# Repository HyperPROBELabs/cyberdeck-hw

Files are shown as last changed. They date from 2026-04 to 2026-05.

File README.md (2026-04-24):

# cyberdeck-hw

Hardware design repository for the Cyberdeck platform
by **Kali Assistant** — HyperPROBE Labs

---

## Overview

This repository contains the **hardware design files** for the Cyberdeck project, including:

* PCB schematics and layouts
* mechanical CAD models
* fabrication and manufacturing data
* supporting hardware resources

The goal is to provide a **modular, reproducible, and hackable hardware platform** for embedded systems, networking, and cybersecurity applications.

---

## Usage

You are free to:

* study the design
* modify and improve it
* manufacture and sell derived hardware
* integrate it into your own systems

Please review the license terms below before use.

---

## Licensing

Unless otherwise specified, this repository is licensed as follows:

### Hardware

All hardware design files are licensed under the
CERN Open Hardware Licence Version 2 - Permissive.

---

### Documentation

All documentation (e.g., manuals, images, diagrams) is licensed under the
Creative Commons Attribution 4.0 International.

---

### Subdirectory Overrides

If a subdirectory contains its own license file or license header:

> **That license takes precedence for files within that subdirectory.**

---

## Attribution

When redistributing or using this work, please attribute:

Kali Assistant

HyperPROBE Labs

---

## Contributing

Contributions are welcome, including:

* hardware improvements
* PCB optimization
* mechanical refinements
* documentation updates

Please ensure:

* proper attribution is maintained
* SPDX license identifiers are included where applicable

---

## Disclaimer

This hardware is provided **"AS IS"**, without warranty of any kind.
Use at your own risk.

---

## Notes

* This is an evolving hardware platform
* Designs may change between revisions
* Not all files are guaranteed to be production-ready

---

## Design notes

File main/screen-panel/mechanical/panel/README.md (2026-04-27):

# Screen Panel

This directory contains the **Cyberdeck Screen Panel (Main)** 3D STEP files and related production resources.

---

## Status

**April 27, 2026**
Design and prototyping in progress.

---

## Directory Structure

```
./production/
├── parts/                 # STEP files for CNC machining and full models
├── mesh-3d-printing/      # STL files for components intended for 3D printing
```

* `./production/parts/`
  Contains STEP files for CNC fabrication and complete mechanical models.

* `./production/mesh-3d-printing/`
  Contains STL meshes for parts that should be 3D printed.

---

## Main Assembly File

* `./pannel.step.xz`

This is the **full screen panel assembly** in STEP format, compressed using `xz` due to file size limitations.

### Usage

```bash
xz -dk panel.step.xz
```

After decompression, import the `.step` file into your preferred CAD software.

---

## Design Notes

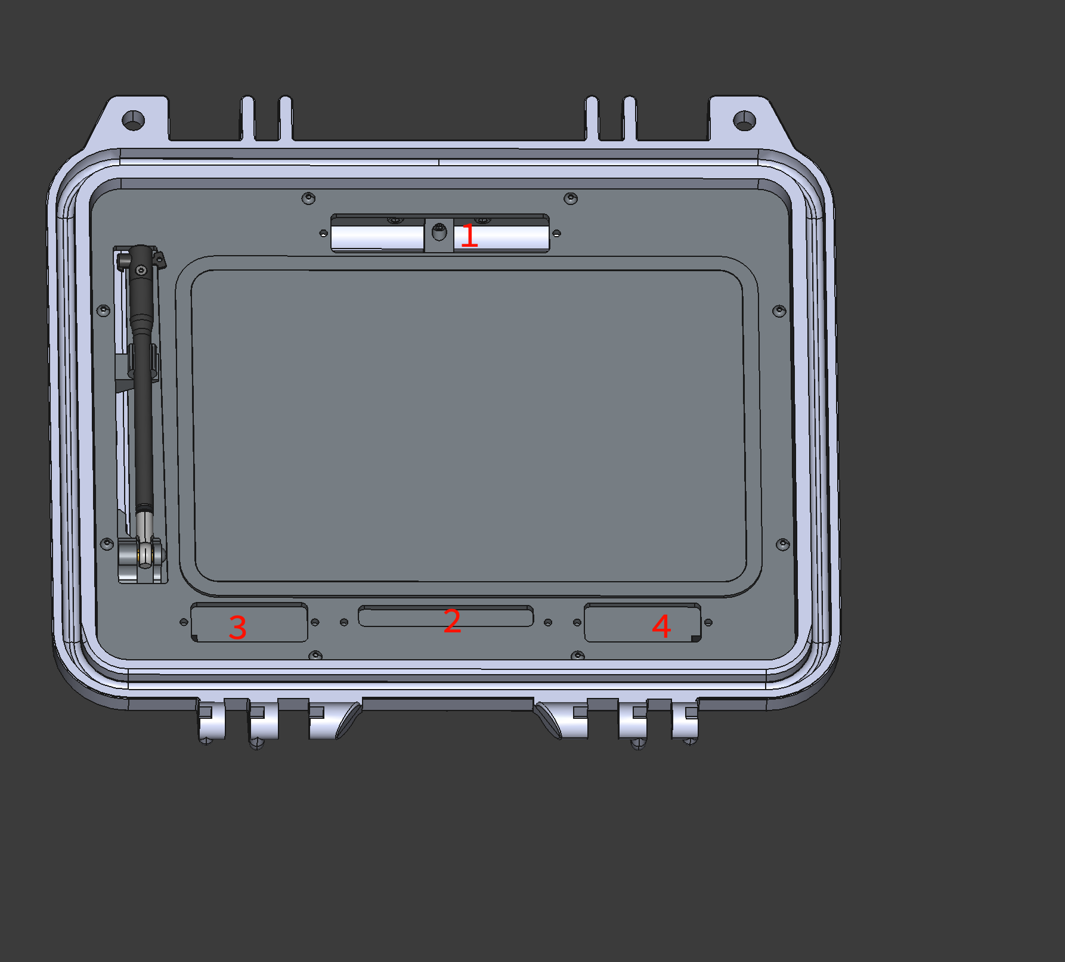
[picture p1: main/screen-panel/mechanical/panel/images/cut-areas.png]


The main plate (aluminum sheet metal) includes several reserved cut areas for future expansion:

### Area 1 — Camera Module (Future)

Reserved cutout for a potential Raspberry Pi camera integration.

### Area 2 — Antenna & Signal Routing

Reserved space for:

* Antenna feed lines
* Flexible Printed Circuits (FPCs)
* Internal signal routing to the Cyberdeck bottom connector

**Note:**
Cables/FPCs are intended to be bundled and protected using TPU, forming a flat, reinforced structure similar to a *flat USB cable* (conceptually: `|:|`).

### Area 3 & 4 — Expansion Modules

Reserved cutouts for optional add-ons, such as:

* Small OLED/TFT displays
* Indicator LEDs
* Buttons or control interfaces

---

## Notes

* This design is modular and intended for iterative hardware expansion.
* Cut areas are intentionally reserved to support future features without redesigning the main plate.
* Mechanical and electrical integration (especially FPC routing) should be considered during assembly.

This project is under active development. Dimensions, cutouts, and interfaces may change between revisions.

---

Cyberdeck Project
Designed by Kali Assistant

Copyright (c) 2026 HyperPROBE Labs. All Rights Reserved.

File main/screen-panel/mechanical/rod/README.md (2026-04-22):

# Screen Panel Support Rod (ROD)

This directory contains the **Cyberdeck Screen Panel Support Rod** 3D STEP files and production resources.

---

# Directory Structure

The repository tree should look like this:

```
/
├── ...
├── docs
│   └── screen-panel-support-rod_manufacturing-and-assembly-manual.pdf
├── main/
│   └── screen-panel/
│       ├── mechanical/
│       │   └── rod/
│       │       ├── production/
│       │       │   ├── bom.csv
│       │       │   ├── mesh-3d-printing/
│       │       │   │   ├── rod-body.stl
│       │       │   │   ├── rod-hat.stl
│       │       │   │   ├── rod-latch.stl
│       │       │   │   └── rod-washer-gasket-multiple-sizes.stl
│       │       │   ├── rod-body.step
│       │       │   ├── rod-hat.step
│       │       │   ├── rod-latch.step
│       │       │   ├── rod-washer-gasket-multiple-sizes.step
│       │       │   └── spring-techdraw.pdf
│       │       ├── README.md
│       │       └── rod.step
│       └── ...
└── ...
```

---

# Production Files

Inside the `production` directory:

* Files located in `mesh-3d-printing/` are **STL mesh files**
* These files are intended for **3D printing manufacturing**
* STEP files are intended for **CNC machining or CAD modification**

---

# Manufacturing

Please read the manufacturing and assembly manual before production:

```
/docs/screen-panel-support-rod_manufacturing-and-assembly-manual.pdf
```

Or open directly:

[`../../../../docs/screen-panel-support-rod_manufacturing-and-assembly-manual.pdf`](../../../../docs/screen-panel-support-rod_manufacturing-and-assembly-manual.pdf)

Refer to the manual for:

* Manufacturing requirements
* Material specifications
* Assembly instructions
* Hardware details

---

# BOM List

The BOM list is located at:

```
production/bom.csv
```

For detailed BOM information, refer to **Section 3** of the [manual](../../../../docs/screen-panel-support-rod_manufacturing-and-assembly-manual.pdf).

---

# BOM Notes

The following notes are used in the BOM file:

* **Available**
  The part can be purchased or imported, but does **not** guarantee stock availability.

* **Not available**
  The part cannot be legally obtained or imported in some countries or regions.

* **Modify REQ**
  Hardware modification required. Not usable out-of-box. Warranty may be void.

* **Import WARN**
  Import may require license, certification, or documentation.

* **Custom**
  Custom-manufactured part. May require MOQ (Minimum Order Quantity).

### Example

* RF modules capable of transmission may require FCC / CE certification depending on region.

---

# License

This directory (`rod`) and the associated documentation:

```
/docs/screen-panel-support-rod_manufacturing-and-assembly-manual.pdf
```

are licensed under:

**CERN-OHL-P v2**

Notes:

* This license applies **only** to the `rod` directory
* The license **may differ** from the root repository license
* If conflicts occur, the license specified in this directory takes precedence

---

# Notes

* STEP files are provided for manufacturing and modification
* STL files are provided for rapid prototyping and 3D printing
* Always review the manual before manufacturing

---

Cyberdeck Project
Designed by KaliAssistant

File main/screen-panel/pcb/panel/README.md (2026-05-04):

# Screen Panel PCB

This directory contains the PCB design and layout files for the Cyberdeck **screen panel module**.

---

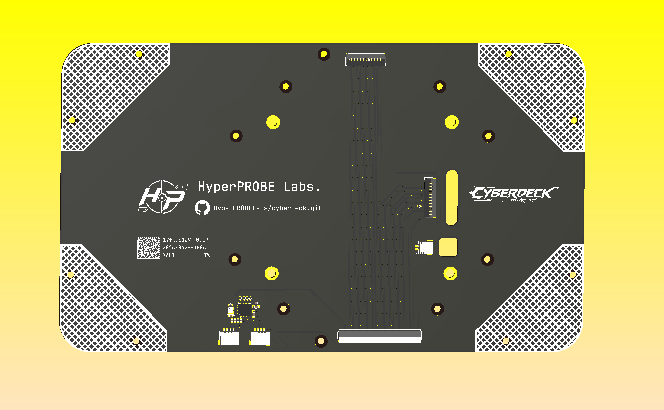
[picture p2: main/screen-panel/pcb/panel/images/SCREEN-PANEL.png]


## Status

**April 29, 2026**
Design and prototyping in progress.

---

## Directory Structure

```
./production/
├── GERBER-*.zip   # Manufacturing files for PCB fabrication
├── BOM-*.csv      # Bill of Materials
└── CPL-*.csv      # Component Placement List (Pick & Place)

./panel-pcb-model*.step.xz  # Compressed 3D STEP model of the PCB
```

---

## 3D Model Usage

Due to GitHub file size limits, the PCB 3D model is compressed using `xz`.

To extract:

```bash
xz -dk panel-pcb-model.step.xz
```

You can then import the `.step` file into your CAD software.

---

## Design Overview

### 50-Pin FPC Integration

The PCB integrates both the camera interface and the Raspberry Pi Touch Display v2 through a **combined 50-pin FPC (Flexible Printed Cable)**.

* FPC design is currently in progress
* Intended to reduce cabling complexity between modules

---

### USB Hub Integration

The board includes a **USB2422 USB hub**, enabling expansion capabilities for the panel.

Two onboard USB expansion module slots are provided for future customization.

---

### Camera Module

Sourcing standalone CMOS sensors is difficult, so the current approach is:

* Use the **Raspberry Pi Camera Module v3 (NoIR)**
* Remove (de-solder) the CMOS module
* Integrate it into this custom PCB design

The camera base and mounting design are still under development.

---

### USB Expansion Modules

Two optional USB-connected addon module slots are included.

Potential use cases:

* Small OLED or TFT displays
* Status indicator LEDs
* Buttons or control interfaces

These modules connect to the onboard USB hub and communicate back to the Cyberdeck motherboard via the 50-pin FPC.

---

## Notes

* This is an actively evolving design
* Hardware, pinout, and module layout may change during prototyping
* Contributions and ideas for USB expansion modules are welcome

---

Cyberdeck Project
Designed by Kali Assistant

Copyright (c) 2026 HyperPROBE Labs. All Rights Reserved.

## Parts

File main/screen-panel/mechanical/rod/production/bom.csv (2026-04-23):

No. | Quantity | Comment | Value | Option | Link | Status
CYB-ROD-001 | 1 | Rod-End-Bearing | M3/1:10RC | (any color) | https://a.co/d/0heQlGqN | Available
CYB-ROD-002 | 1 | Metric Flat Washer | M3 D6/3.2 T0.5 | M3x6mmx0.5mm | https://a.co/d/0e98ipRb | Available
CYB-ROD-003 | 1 | TPU Gasket | -- | -- | -- | Custom
CYB-ROD-004 | 1 | Rod-Body | -- | -- | -- | Custom
CYB-ROD-005 | 1 | Metric Hex Nut | M2x0.4x1.2 | M2 50pcs | https://a.co/d/08POY6ck | Available
CYB-ROD-006 | 1 | Torsion Spring | -- | -- | -- | Custom
CYB-ROD-007 | 1 | Rod-Latch | -- | -- | -- | Custom
CYB-ROD-008 | 1 | Rod-Hat | -- | -- | -- | Custom
CYB-ROD-009 | 1 | Ultra-Low Head Hexalobular Screw | M2x0.4x8 | 50pcs M2/8mm | https://a.co/d/05IATbxW | Available

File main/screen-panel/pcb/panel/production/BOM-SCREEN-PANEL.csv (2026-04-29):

Comment | Designator | Footprint | LCSC | Quantity
100nF | C1,C4,C5 | C_0402_1005Metric | C437421 | 3
10k | R3 | R_0402_1005Metric | C71617 | 1
10nF | C6 | C_0402_1005Metric | C85973 | 1
12k | R2 | R_0402_1005Metric | C481938 | 1
18pF | C7,C8 | C_0402_1005Metric | C161176 | 2
1uF | C2,C3 | C_0603_1608Metric | C77386 | 2
24Mhz | X1 | CRYSTAL-SMD_4P-L2.0-W1.6-BL | C255882 | 1
2k2 | R1 | R_0402_1005Metric | C82680 | 1
47k | R4,R5,R6 | R_0402_1005Metric | C482184 | 3
BUS | FPC2 | FPC-SMD_50P-P0.50_FH34SRJ-50S-0.5SH | C3169104 | 1
SM02B-SRSS-TB | CN1 | CONN-SMD_2P-P1.00_SM02B-SRSS-TB-LF-SN | C160402 | 1
SM04B-SRSS-TB | CN2,CN3 | CONN-SMD_4P-P1.00_SM04B-SRSS-TB-LF-SN | C160404 | 2
USB2422/MJ | U1 | QFN-24_L4.0-W4.0-P0.50-BL-EP2.6 | C633330 | 1
~ | FPC1,FPC3 | FFC-SMD_22P-P0.50_HRS_FH34SRJ-22S-0.5SH | C2889325 | 2

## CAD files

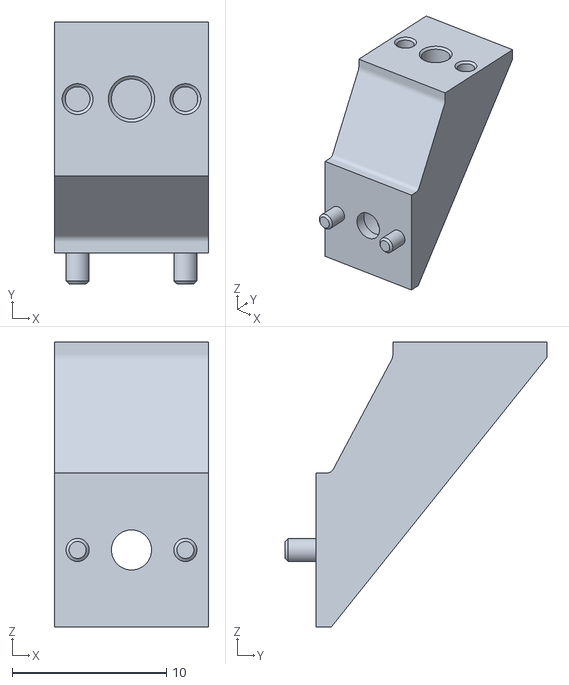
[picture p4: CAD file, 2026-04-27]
main/screen-panel/mechanical/panel/production/mesh-3d-printing/main-frame-angle-bracket.stl
10.0 x 17.0 x 18.5

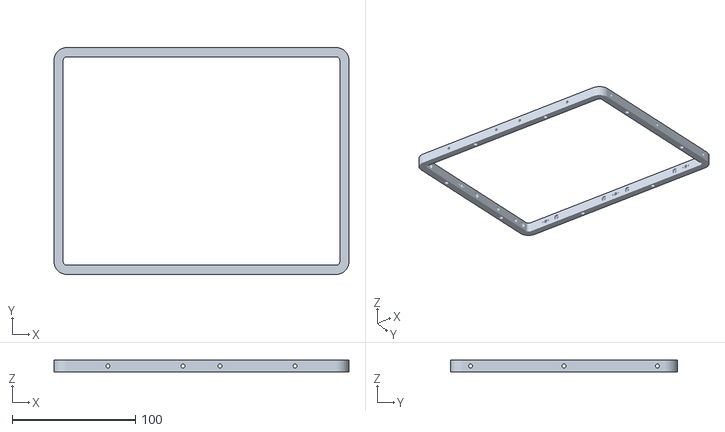
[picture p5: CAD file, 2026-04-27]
main/screen-panel/mechanical/panel/production/mesh-3d-printing/main-frame.stl
239.5 x 184.2 x 10.0

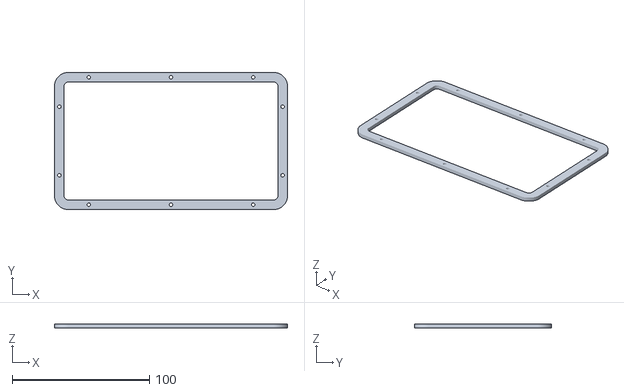
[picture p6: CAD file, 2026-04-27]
main/screen-panel/mechanical/panel/production/mesh-3d-printing/screen-main-base-frame.stl
170.0 x 100.0 x 3.00

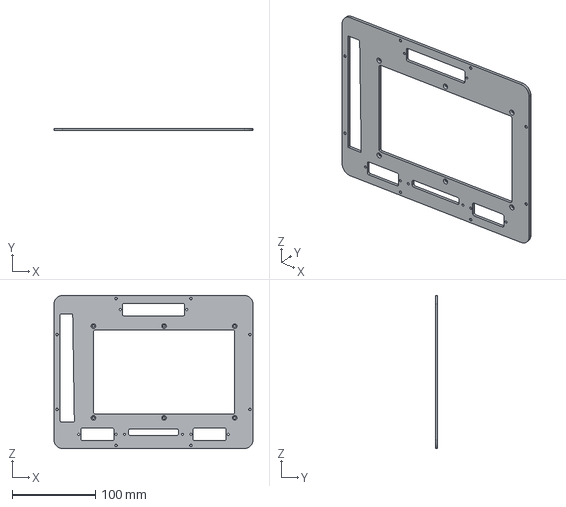
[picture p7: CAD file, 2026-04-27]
main/screen-panel/mechanical/panel/production/parts/main-plate.step
239.5 x 3.00 x 184.2 mm

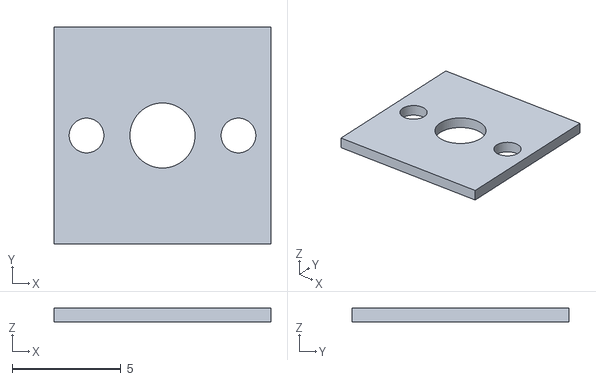
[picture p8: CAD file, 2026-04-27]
main/screen-panel/mechanical/panel/production/mesh-3d-printing/main-frame-angle-bracket-tpu.stl
10.0 x 10.0 x 0.65

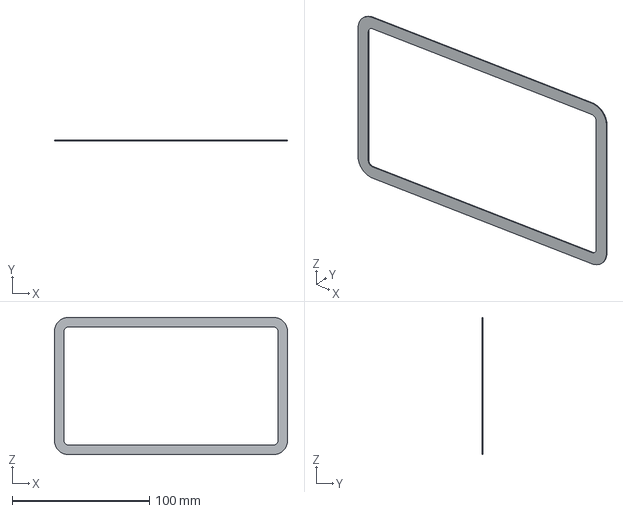
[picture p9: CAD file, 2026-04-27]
main/screen-panel/mechanical/panel/production/parts/screen-main-base-frame-tpu.step
170.0 x 0.55 x 100.0 mm

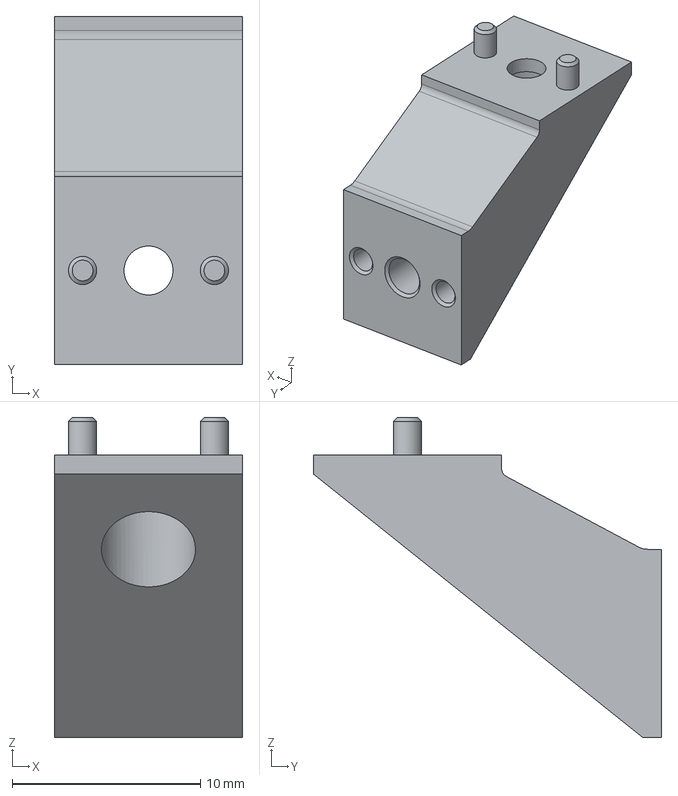
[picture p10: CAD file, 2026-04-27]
main/screen-panel/mechanical/panel/production/parts/main-frame-angle-bracket.step
10.0 x 18.5 x 17.0 mm

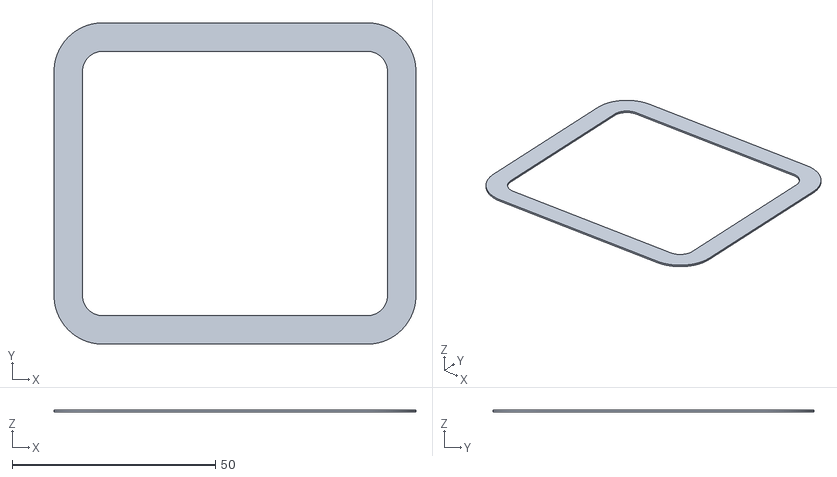
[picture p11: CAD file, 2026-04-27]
main/screen-panel/mechanical/panel/production/mesh-3d-printing/screen-base-tpu.stl
89.0 x 79.0 x 0.55

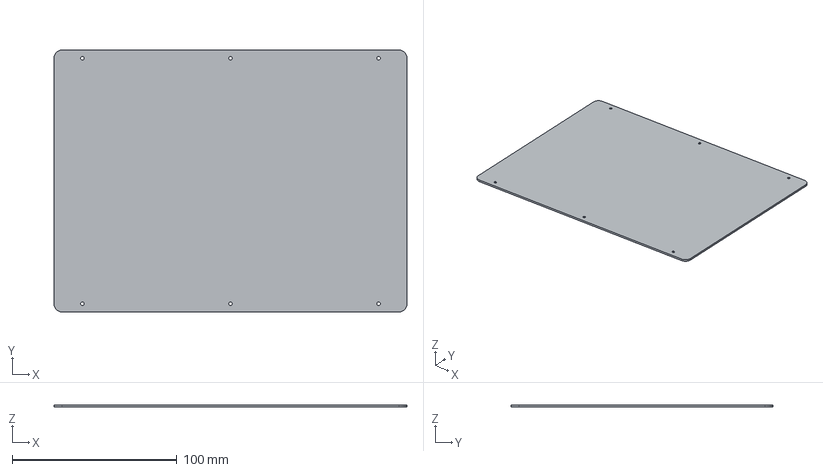
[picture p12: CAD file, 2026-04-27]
main/screen-panel/mechanical/panel/production/parts/base-plate.step
214.5 x 159.2 x 1.50 mm

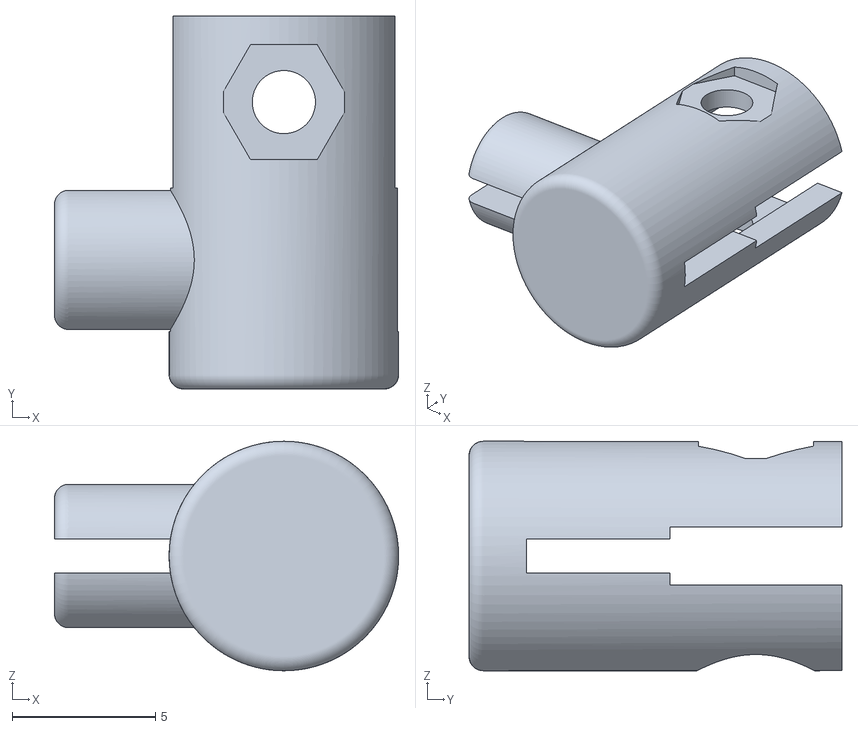
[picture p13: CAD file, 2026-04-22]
main/screen-panel/mechanical/rod/production/mesh-3d-printing/rod-hat.stl
12.0 x 13.0 x 8.00

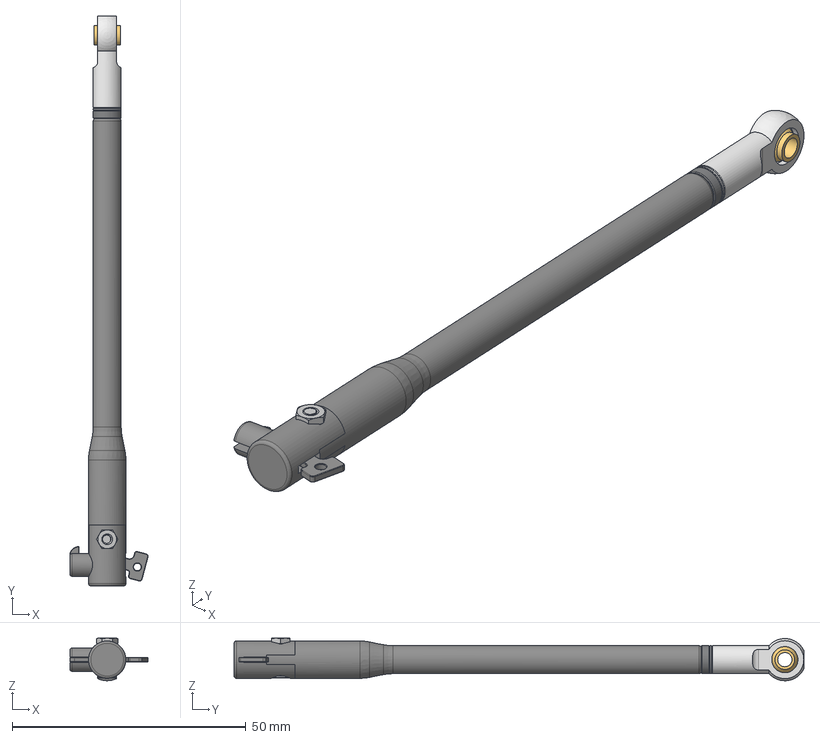
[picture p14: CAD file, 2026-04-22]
main/screen-panel/mechanical/rod/rod.step
16.8 x 121.9 x 9.13 mm
ROLLER
BEARING-HOUSING
BODY-SS316L
LATCH-SS316L
SPRING
CONN-SS316L
TORX-M2-L8MM
NUT-M2-L1MM2
WASHER-PA12
WASHER-SS

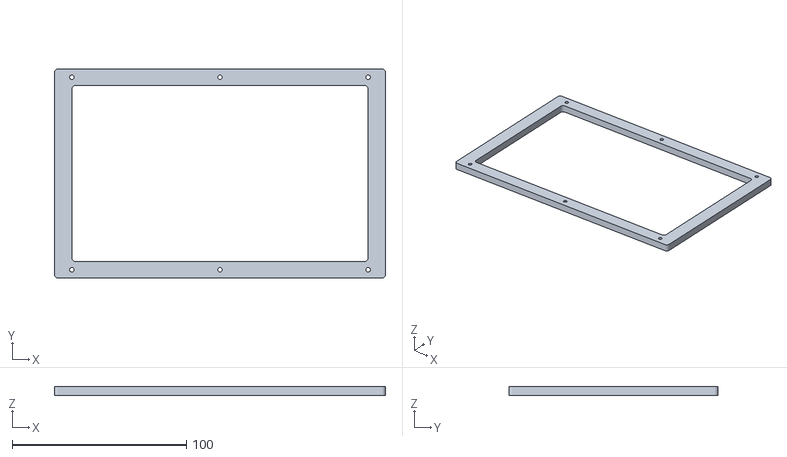
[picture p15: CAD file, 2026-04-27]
main/screen-panel/mechanical/panel/production/mesh-3d-printing/screen-frame.stl
190.0 x 120.0 x 5.00

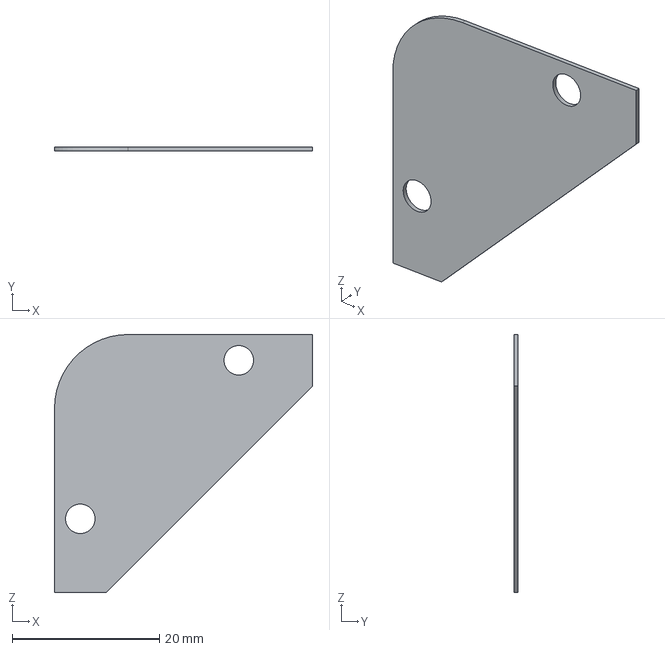
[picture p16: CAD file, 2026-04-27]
main/screen-panel/mechanical/panel/production/parts/screen-angle-bracket-tpu.step
35.0 x 0.55 x 35.0 mm

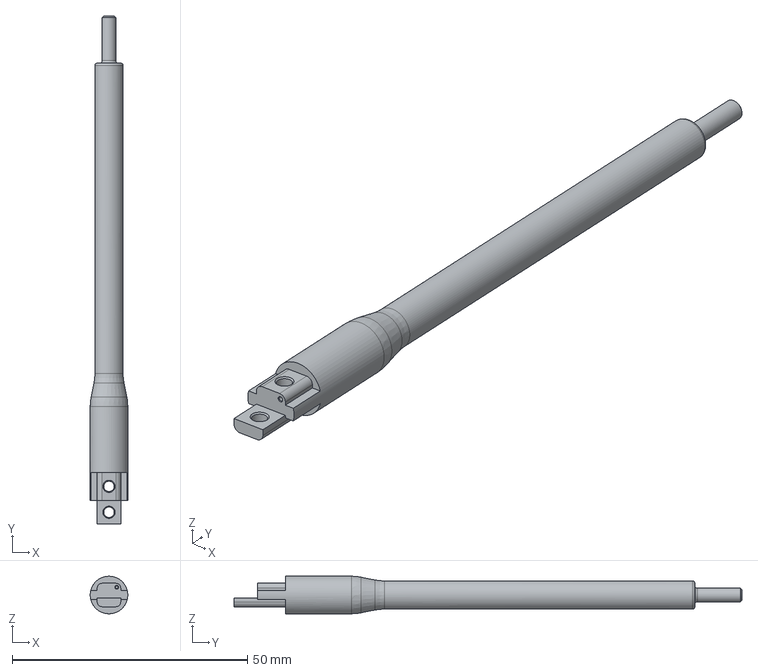
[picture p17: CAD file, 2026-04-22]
main/screen-panel/mechanical/rod/production/rod-body.step
8.00 x 108.0 x 8.00 mm

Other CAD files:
main/screen-panel/mechanical/panel/production/parts/main-frame.step
main/screen-panel/mechanical/panel/production/mesh-3d-printing/screen-main-base-frame-tpu.stl
main/screen-panel/mechanical/panel/production/parts/screen-main-base-frame.step
main/screen-panel/mechanical/panel/production/parts/main-frame-angle-bracket-tpu.step
main/screen-panel/mechanical/panel/production/mesh-3d-printing/rod-holder.stl
main/screen-panel/mechanical/panel/production/mesh-3d-printing/screen-angle-bracket-tpu.stl
main/screen-panel/mechanical/panel/production/mesh-3d-printing/screen-angle-bracket.stl
main/screen-panel/mechanical/panel/production/mesh-3d-printing/screen-base-frame.stl
main/screen-panel/mechanical/panel/production/mesh-3d-printing/screen-tpu.stl
main/screen-panel/mechanical/panel/production/parts/rod-base.step
main/screen-panel/mechanical/panel/production/parts/rod-holder.step
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

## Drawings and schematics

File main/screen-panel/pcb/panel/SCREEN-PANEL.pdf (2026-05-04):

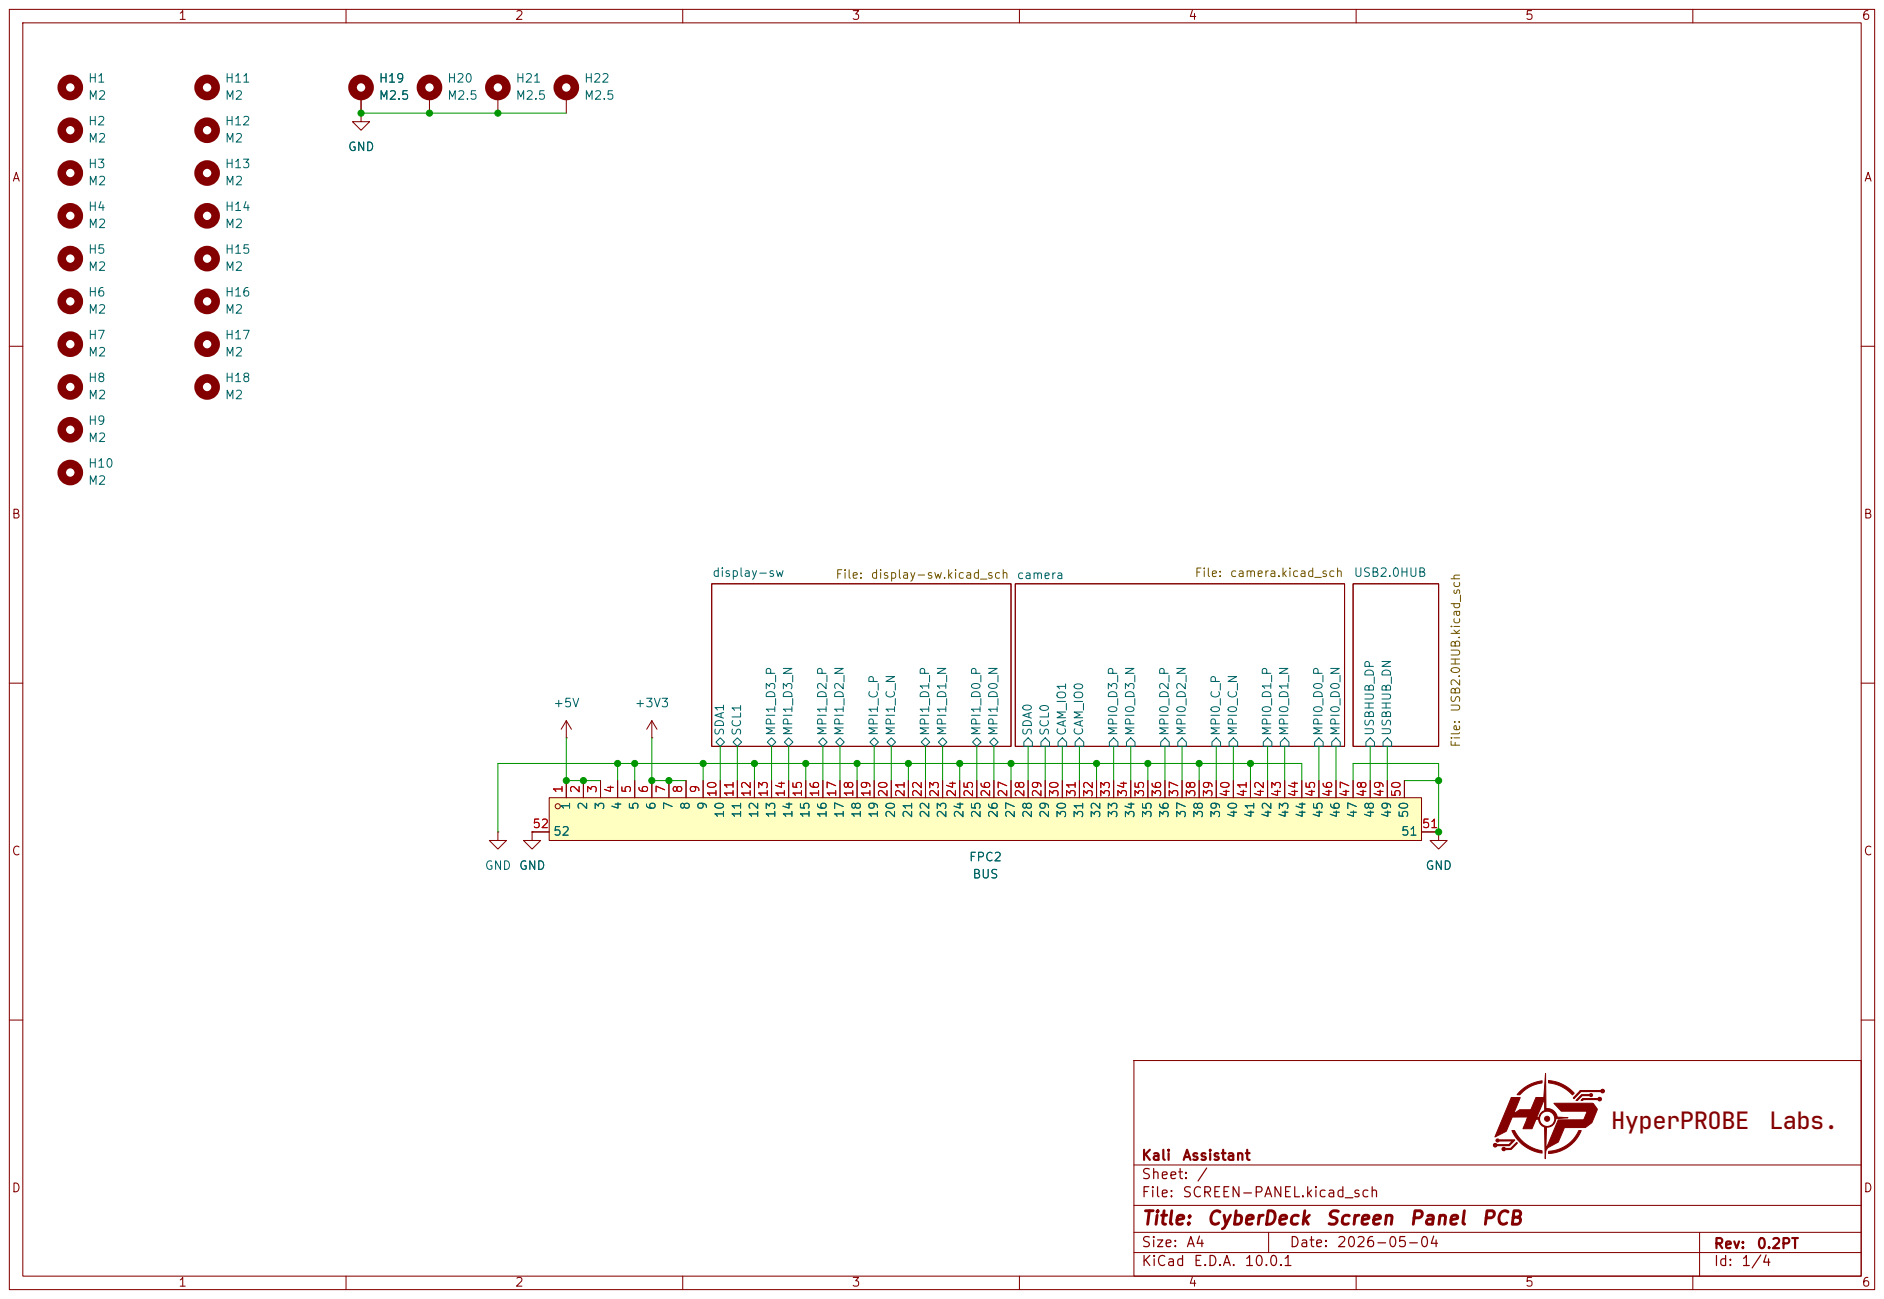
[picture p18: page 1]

Kali Assistant
Sheet: /
File: SCREEN-PANEL.kicad_sch
Title: CyberDeck Screen Panel PCB

Size: A4 | Rev: 0.2PT
KiCad E.D.A. 10.0.1 | Id: 1/4

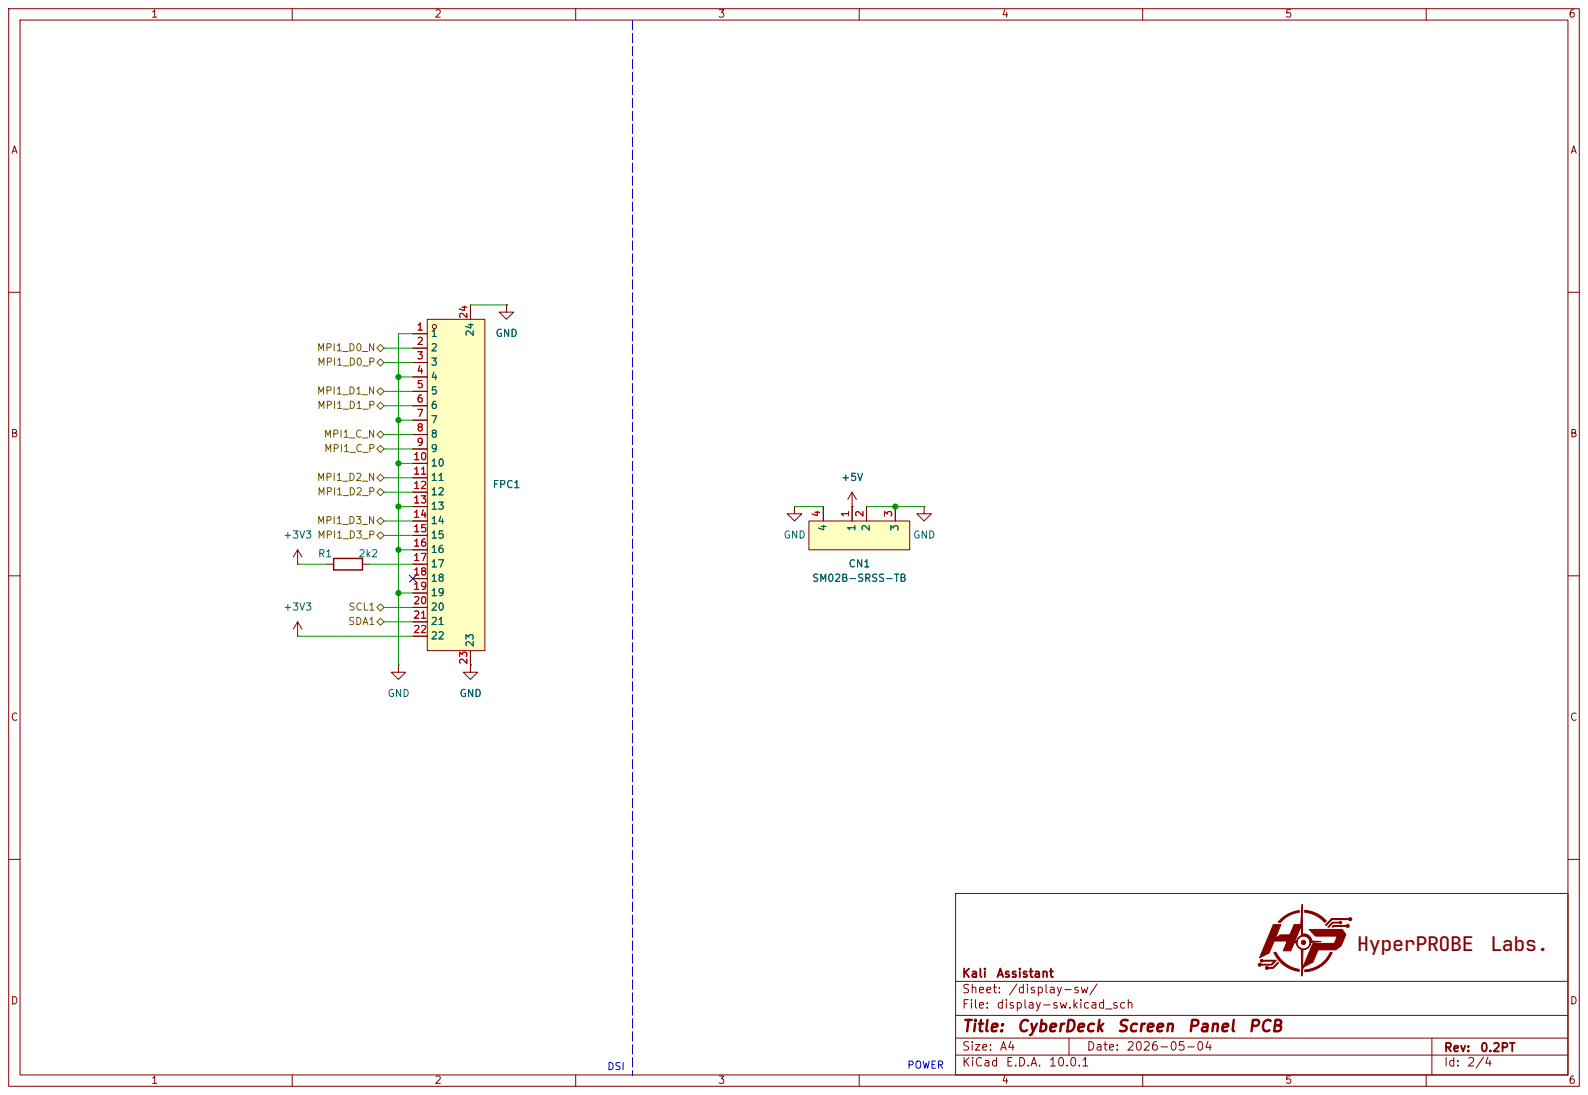
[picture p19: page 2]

Kali Assistant
Sheet: /display-sw/
File: display-sw.kicad_sch
Title: CyberDeck Screen Panel PCB

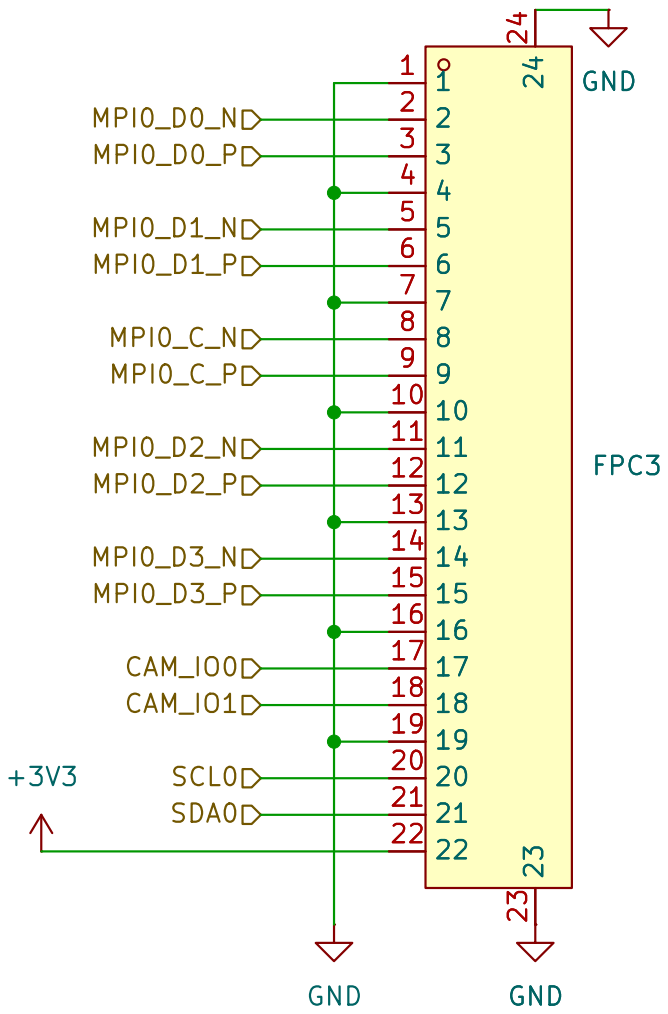
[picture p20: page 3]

Kali Assistant
Sheet: /camera/
File: camera.kicad_sch
Title: CyberDeck Screen Panel PCB

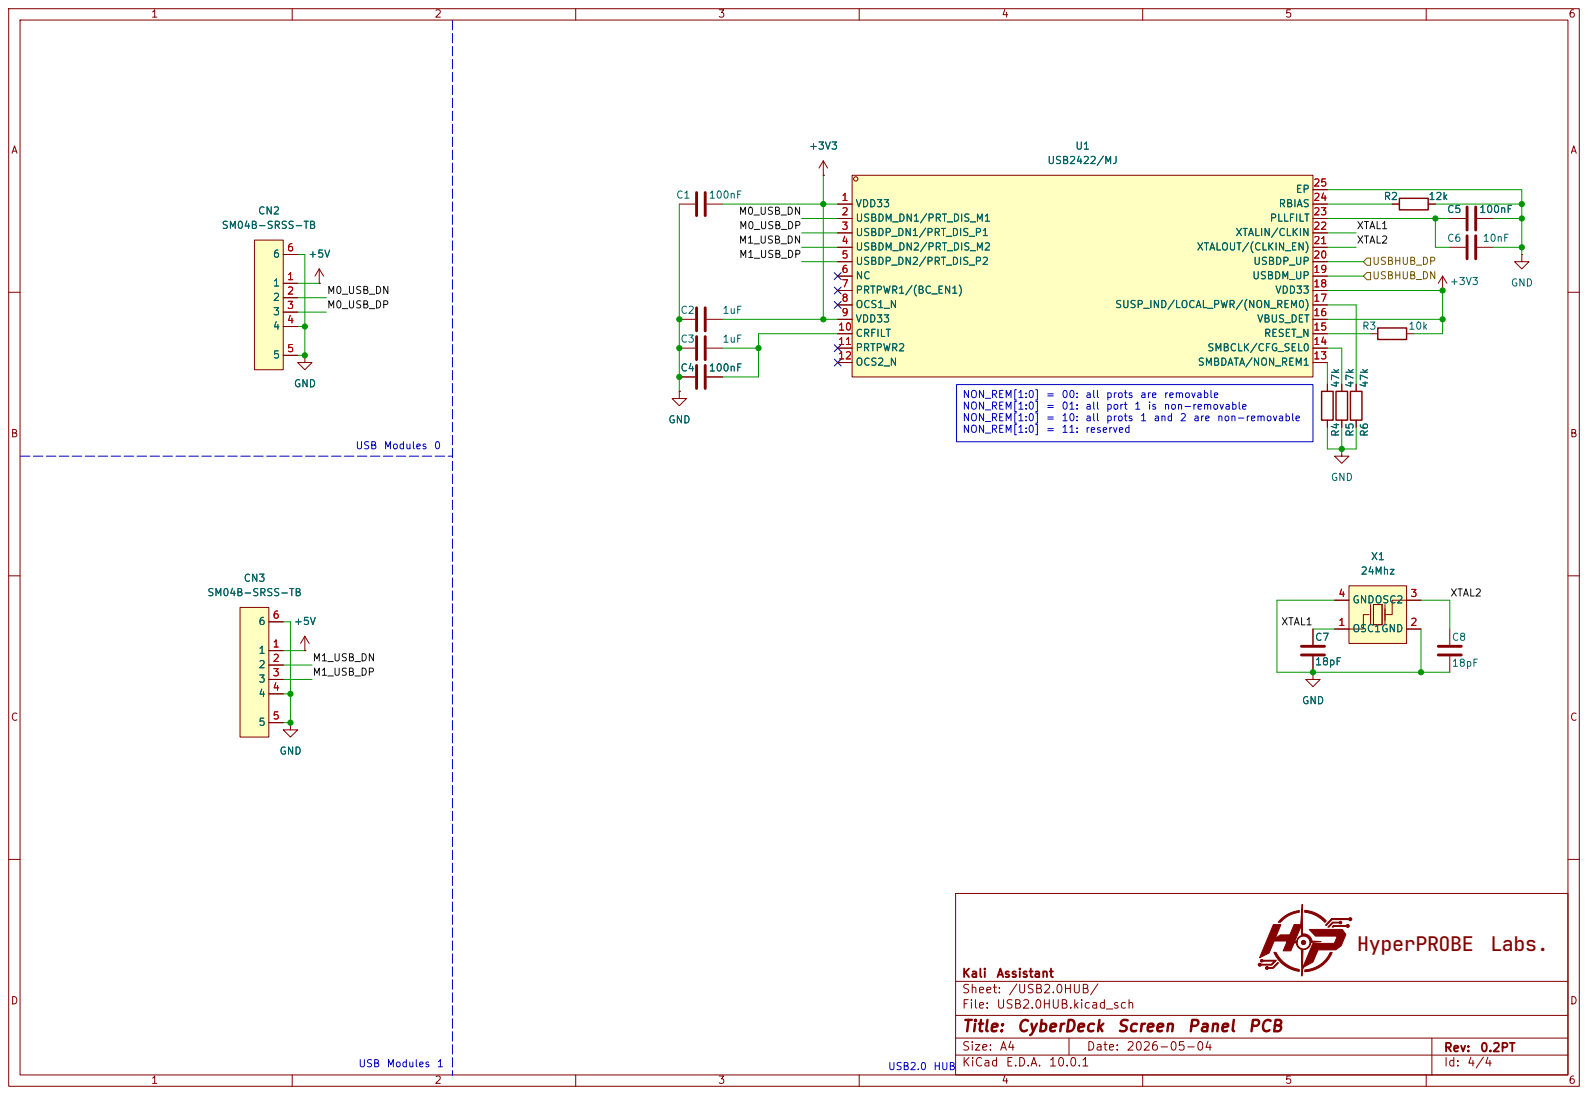
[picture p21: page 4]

Kali Assistant
Sheet: /USB2.0HUB/
File: USB2.0HUB.kicad_sch
Title: CyberDeck Screen Panel PCB

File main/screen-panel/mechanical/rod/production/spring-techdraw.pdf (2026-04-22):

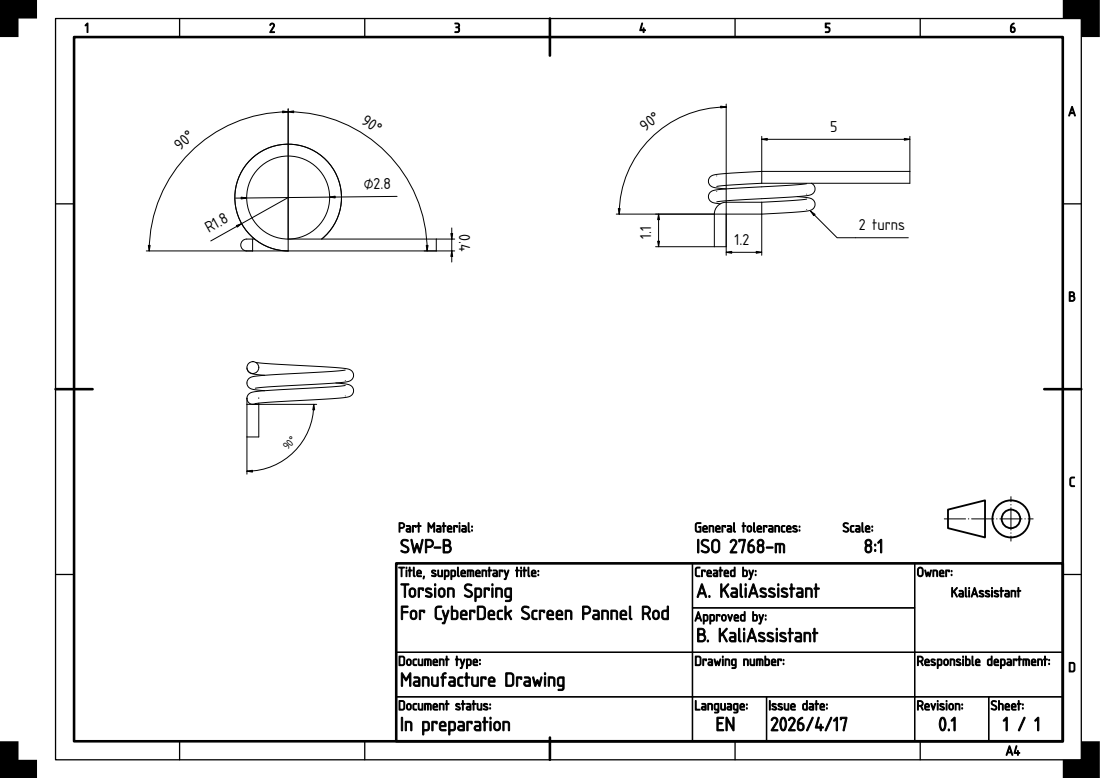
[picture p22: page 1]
2 turn

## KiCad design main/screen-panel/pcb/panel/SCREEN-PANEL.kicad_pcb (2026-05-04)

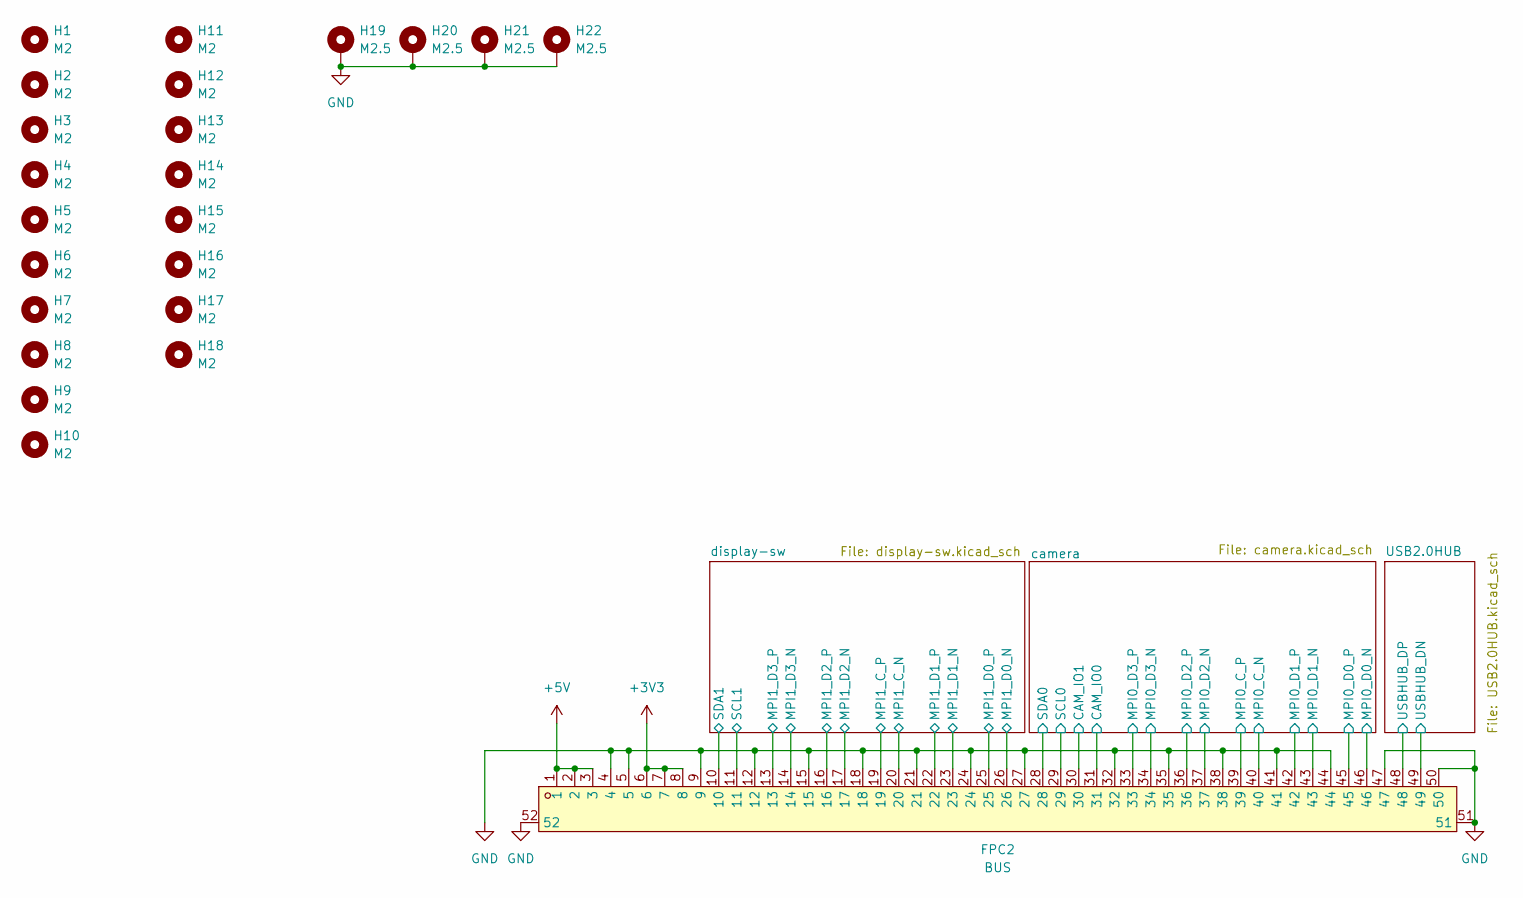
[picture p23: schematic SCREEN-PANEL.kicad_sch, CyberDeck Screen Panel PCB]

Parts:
FPC2: BUS; FPC-SMD_50P-P0.50_FH34SRJ-50S-0.5SH; MPN FH34SRJ-50S-0.5SH(50); LCSC Part C3169104
H1, H2, H3, H4, H5, H6, H7, H8, H9, H10, H11, H12, H13, H14, H15, H16, H17, H18: M2; MountingHole_2.2mm_M2_ISO14580
H19, H20, H21, H22: M2.5; MountingHole_2.7mm_M2.5_ISO14580_Pad

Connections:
+3V3: FPC2.6, FPC2.7, FPC2.8; also elsewhere on the board
+5V: FPC2.1, FPC2.2, FPC2.3; also elsewhere on the board
/USB2.0HUB/USBHUB_DN: FPC2.49; also elsewhere on the board
/USB2.0HUB/USBHUB_DP: FPC2.48; also elsewhere on the board
/camera/CAM_IO0: FPC2.31; also elsewhere on the board
/camera/CAM_IO1: FPC2.30; also elsewhere on the board
/camera/MPI0_C_N: FPC2.40; also elsewhere on the board
/camera/MPI0_C_P: FPC2.39; also elsewhere on the board
/camera/MPI0_D0_N: FPC2.46; also elsewhere on the board
/camera/MPI0_D0_P: FPC2.45; also elsewhere on the board
/camera/MPI0_D1_N: FPC2.43; also elsewhere on the board
/camera/MPI0_D1_P: FPC2.42; also elsewhere on the board
/camera/MPI0_D2_N: FPC2.37; also elsewhere on the board
/camera/MPI0_D2_P: FPC2.36; also elsewhere on the board
/camera/MPI0_D3_N: FPC2.34; also elsewhere on the board
/camera/MPI0_D3_P: FPC2.33; also elsewhere on the board
/camera/SCL0: FPC2.29; also elsewhere on the board
/camera/SDA0: FPC2.28; also elsewhere on the board
/display-sw/MPI1_C_N: FPC2.20; also elsewhere on the board
/display-sw/MPI1_C_P: FPC2.19; also elsewhere on the board
/display-sw/MPI1_D0_N: FPC2.26; also elsewhere on the board
/display-sw/MPI1_D0_P: FPC2.25; also elsewhere on the board
/display-sw/MPI1_D1_N: FPC2.23; also elsewhere on the board
/display-sw/MPI1_D1_P: FPC2.22; also elsewhere on the board
/display-sw/MPI1_D2_N: FPC2.17; also elsewhere on the board
/display-sw/MPI1_D2_P: FPC2.16; also elsewhere on the board
/display-sw/MPI1_D3_N: FPC2.14; also elsewhere on the board
/display-sw/MPI1_D3_P: FPC2.13; also elsewhere on the board
/display-sw/SCL1: FPC2.11; also elsewhere on the board
/display-sw/SDA1: FPC2.10; also elsewhere on the board
GND: FPC2.4, FPC2.5, FPC2.9, FPC2.12, FPC2.15, FPC2.18, FPC2.21, FPC2.24, FPC2.27, FPC2.32, FPC2.35, FPC2.38, FPC2.41, FPC2.44, FPC2.47, FPC2.50, FPC2.51, FPC2.52, H19.1 (1_1), H20.1 (1_1), H21.1 (1_1), H22.1 (1_1); also elsewhere on the board

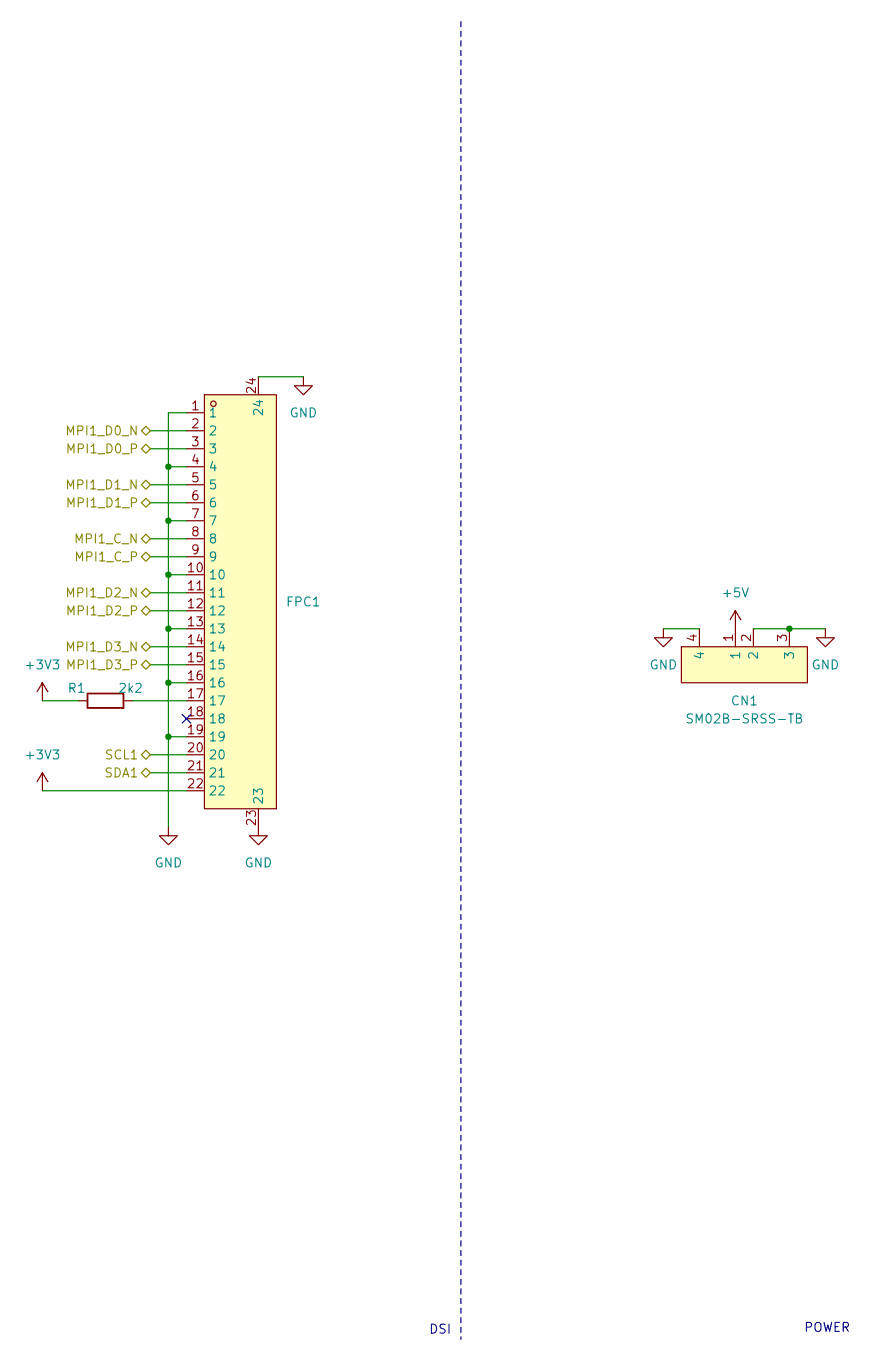
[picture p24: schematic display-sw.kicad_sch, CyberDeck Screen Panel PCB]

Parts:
CN1: SM02B-SRSS-TB; CONN-SMD_2P-P1.00_SM02B-SRSS-TB-LF-SN; MPN SM02B-SRSS-TB(LF)(SN); LCSC Part C160402
FPC1: FFC-SMD_22P-P0.50_HRS_FH34SRJ-22S-0.5SH; MPN FH34SRJ-22S-0.5SH(50); LCSC Part C2889325
R1: 2k2; R_0402_1005Metric

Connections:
+3V3: FPC1.22, R1.1; also elsewhere on the board
+5V: CN1.1; also elsewhere on the board
/display-sw/MPI1_C_N: FPC1.8; also elsewhere on the board
/display-sw/MPI1_C_P: FPC1.9; also elsewhere on the board
/display-sw/MPI1_D0_N: FPC1.2; also elsewhere on the board
/display-sw/MPI1_D0_P: FPC1.3; also elsewhere on the board
/display-sw/MPI1_D1_N: FPC1.5; also elsewhere on the board
/display-sw/MPI1_D1_P: FPC1.6; also elsewhere on the board
/display-sw/MPI1_D2_N: FPC1.11; also elsewhere on the board
/display-sw/MPI1_D2_P: FPC1.12; also elsewhere on the board
/display-sw/MPI1_D3_N: FPC1.14; also elsewhere on the board
/display-sw/MPI1_D3_P: FPC1.15; also elsewhere on the board
/display-sw/SCL1: FPC1.20; also elsewhere on the board
/display-sw/SDA1: FPC1.21; also elsewhere on the board
GND: CN1.2, CN1.3, CN1.4, FPC1.1, FPC1.4, FPC1.7, FPC1.10, FPC1.13, FPC1.16, FPC1.19, FPC1.23, FPC1.24; also elsewhere on the board
unnamed: FPC1.17, R1.2

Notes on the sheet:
DSI
POWER

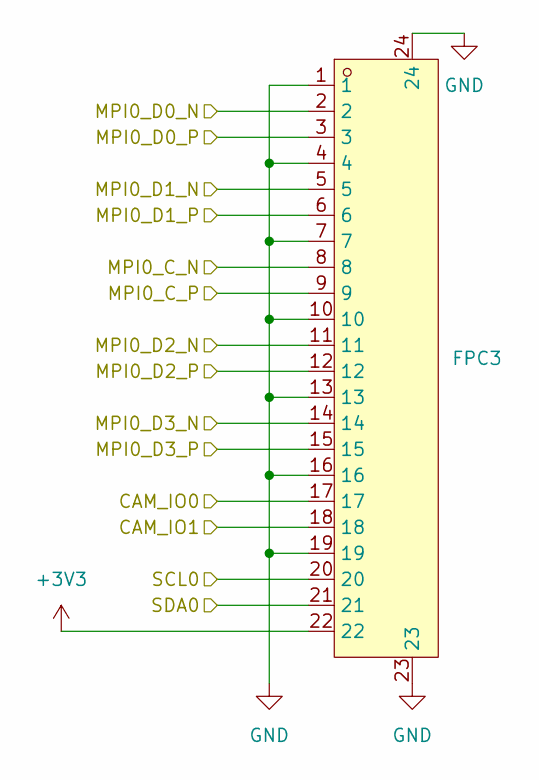
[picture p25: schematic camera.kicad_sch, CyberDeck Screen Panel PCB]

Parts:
FPC3: FFC-SMD_22P-P0.50_HRS_FH34SRJ-22S-0.5SH; MPN FH34SRJ-22S-0.5SH(50); LCSC Part C2889325

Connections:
+3V3: FPC3.22; also elsewhere on the board
/camera/CAM_IO0: FPC3.17; also elsewhere on the board
/camera/CAM_IO1: FPC3.18; also elsewhere on the board
/camera/MPI0_C_N: FPC3.8; also elsewhere on the board
/camera/MPI0_C_P: FPC3.9; also elsewhere on the board
/camera/MPI0_D0_N: FPC3.2; also elsewhere on the board
/camera/MPI0_D0_P: FPC3.3; also elsewhere on the board
/camera/MPI0_D1_N: FPC3.5; also elsewhere on the board
/camera/MPI0_D1_P: FPC3.6; also elsewhere on the board
/camera/MPI0_D2_N: FPC3.11; also elsewhere on the board
/camera/MPI0_D2_P: FPC3.12; also elsewhere on the board
/camera/MPI0_D3_N: FPC3.14; also elsewhere on the board
/camera/MPI0_D3_P: FPC3.15; also elsewhere on the board
/camera/SCL0: FPC3.20; also elsewhere on the board
/camera/SDA0: FPC3.21; also elsewhere on the board
GND: FPC3.1, FPC3.4, FPC3.7, FPC3.10, FPC3.13, FPC3.16, FPC3.19, FPC3.23, FPC3.24; also elsewhere on the board

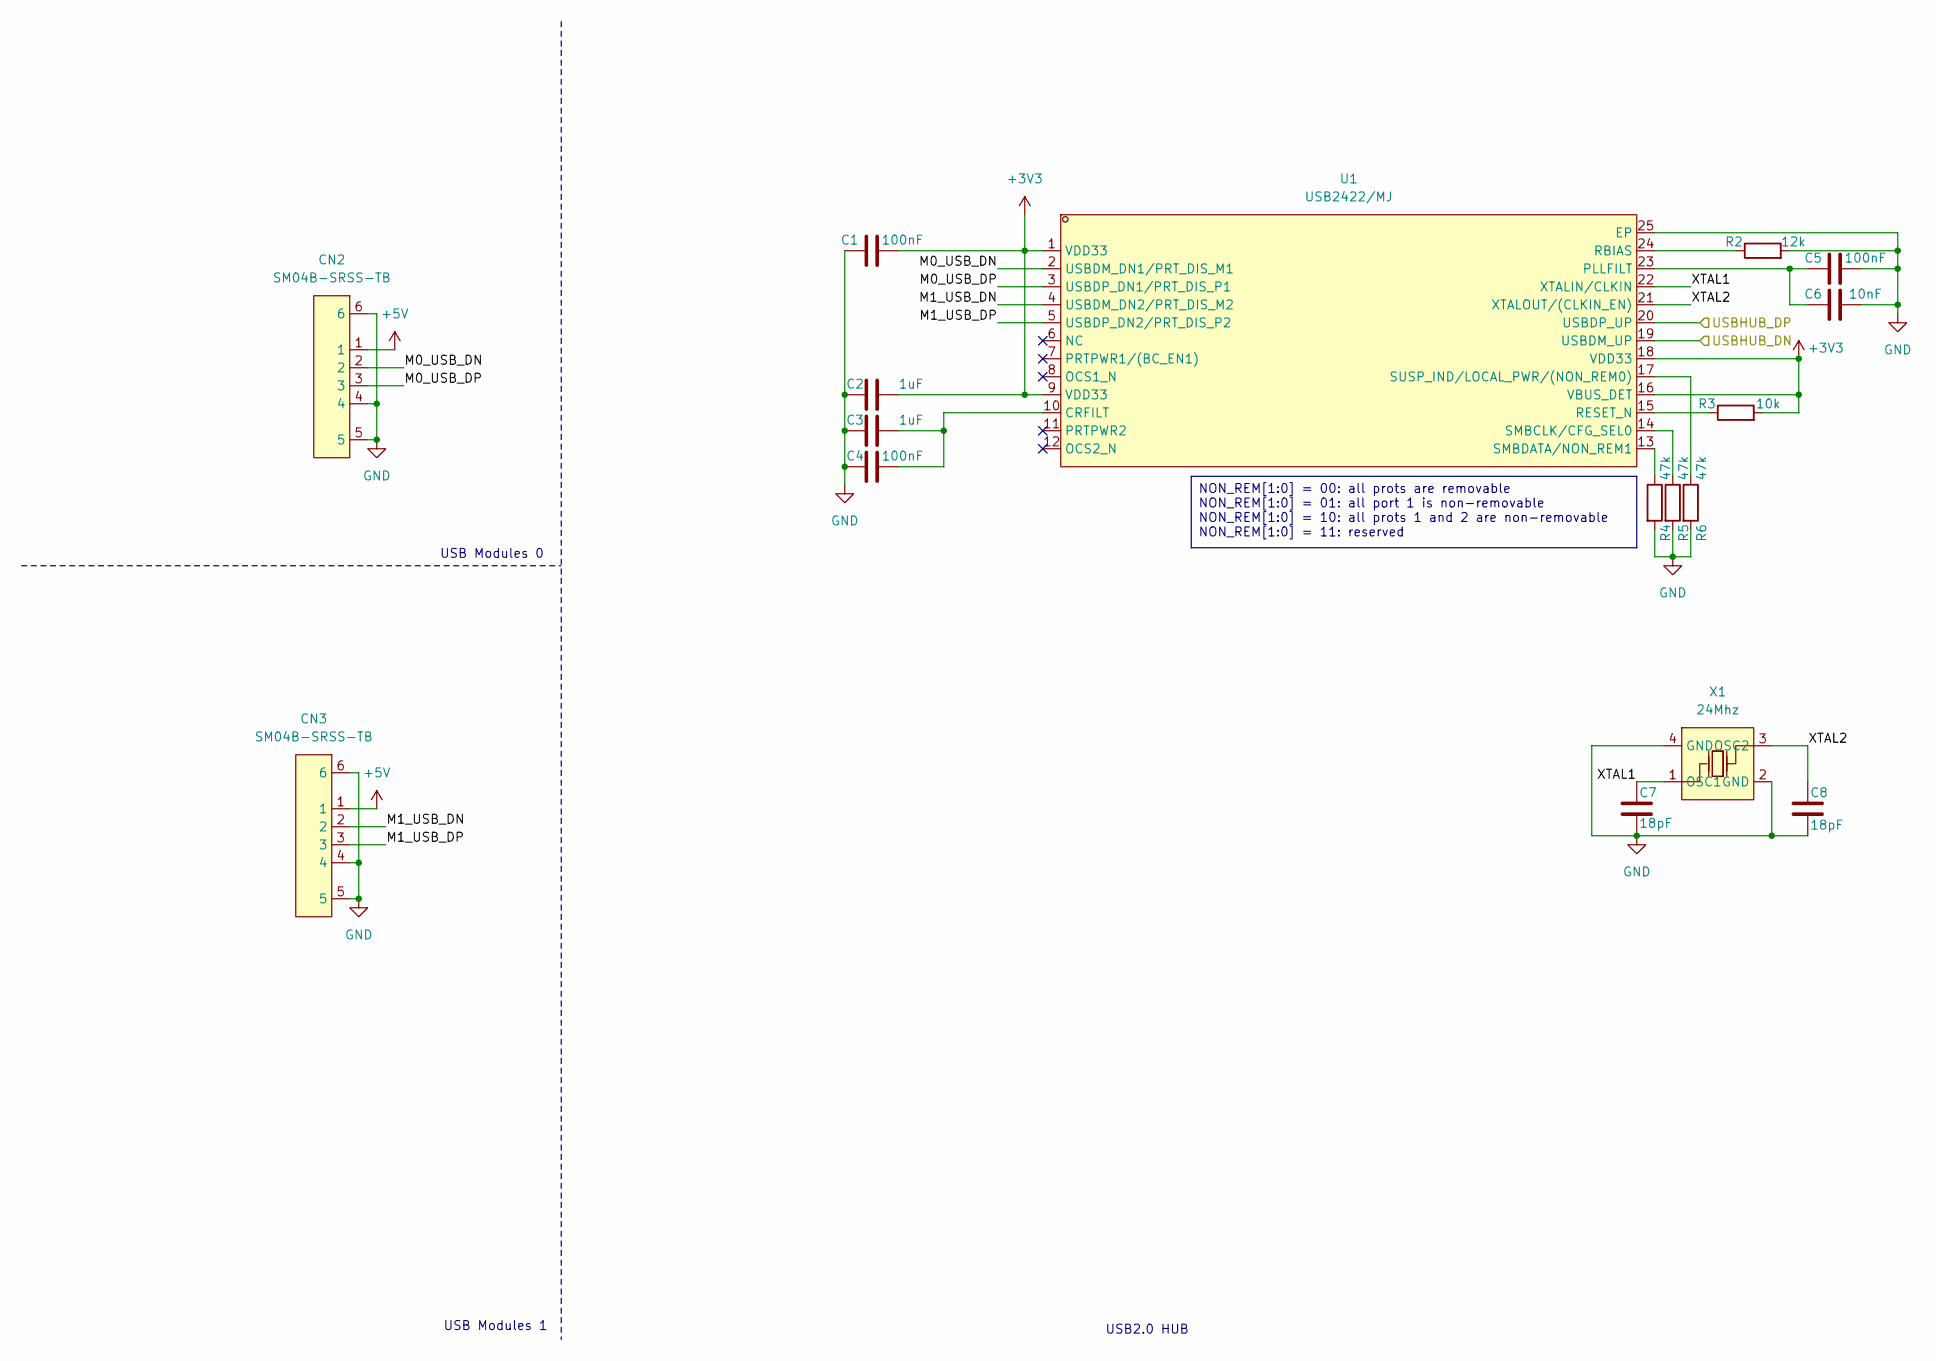
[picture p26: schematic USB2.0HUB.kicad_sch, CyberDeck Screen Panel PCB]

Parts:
C1, C4, C5: 100nF; C_0402_1005Metric
C2, C3: 1uF; C_0603_1608Metric
C6: 10nF; C_0402_1005Metric
C7, C8: 18pF; C_0402_1005Metric
CN2, CN3: SM04B-SRSS-TB; CONN-SMD_4P-P1.00_SM04B-SRSS-TB-LF-SN; MPN SM04B-SRSS-TB(LF)(SN); LCSC Part C160404
R2: 12k; R_0402_1005Metric
R3: 10k; R_0402_1005Metric
R4, R5, R6: 47k; R_0402_1005Metric
U1: USB2422/MJ; QFN-24_L4.0-W4.0-P0.50-BL-EP2.6; MPN USB2422/MJ; LCSC Part C633330
X1: 24Mhz; CRYSTAL-SMD_4P-L2.0-W1.6-BL; MPN Q22FA12800489; LCSC Part C255882

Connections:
+3V3: C1.2, C2.2, R3.2, U1.1 (VDD33), U1.9 (VDD33), U1.16 (VBUS_DET), U1.18 (VDD33); also elsewhere on the board
+5V: CN2.1, CN3.1; also elsewhere on the board
/USB2.0HUB/M0_USB_DN: CN2.2, U1.2 (USBDM_DN1/PRT_DIS_M1)
/USB2.0HUB/M0_USB_DP: CN2.3, U1.3 (USBDP_DN1/PRT_DIS_P1)
/USB2.0HUB/M1_USB_DN: CN3.2, U1.4 (USBDM_DN2/PRT_DIS_M2)
/USB2.0HUB/M1_USB_DP: CN3.3, U1.5 (USBDP_DN2/PRT_DIS_P2)
/USB2.0HUB/USBHUB_DN: U1.19 (USBDM_UP); also elsewhere on the board
/USB2.0HUB/USBHUB_DP: U1.20 (USBDP_UP); also elsewhere on the board
/USB2.0HUB/XTAL1: C7.1, U1.22 (XTALIN/CLKIN), X1.1 (OSC1)
/USB2.0HUB/XTAL2: C8.1, U1.21 (XTALOUT/(CLKIN_EN)), X1.3 (OSC2)
GND: C1.1, C2.1, C3.1, C4.1, C5.2, C6.2, C7.2, C8.2, CN2.4, CN2.5, CN2.6, CN3.4, CN3.5, CN3.6, R2.2, R4.2, R5.2, R6.2, U1.25 (EP), X1.2 (GND), X1.4 (GND); also elsewhere on the board
unnamed: C3.2, C4.2, U1.10 (CRFILT)
unnamed: C5.1, C6.1, U1.23 (PLLFILT)
unnamed: R2.1, U1.24 (RBIAS)
unnamed: R3.1, U1.15 (RESET_N)
unnamed: R5.1, U1.14 (SMBCLK/CFG_SEL0)
unnamed: R4.1, U1.13 (SMBDATA/NON_REM1)
unnamed: R6.1, U1.17 (SUSP_IND/LOCAL_PWR/(NON_REM0))

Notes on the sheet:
USB2.0 HUB
USB Modules 1
USB Modules 0
NON_REM[1:0] = 00: all prots are removable NON_REM[1:0] = 01: all port 1 is non-removable NON_REM[1:0] = 10: all prots 1 and 2 are non-removable NON_REM[1:0] = 11: reserved

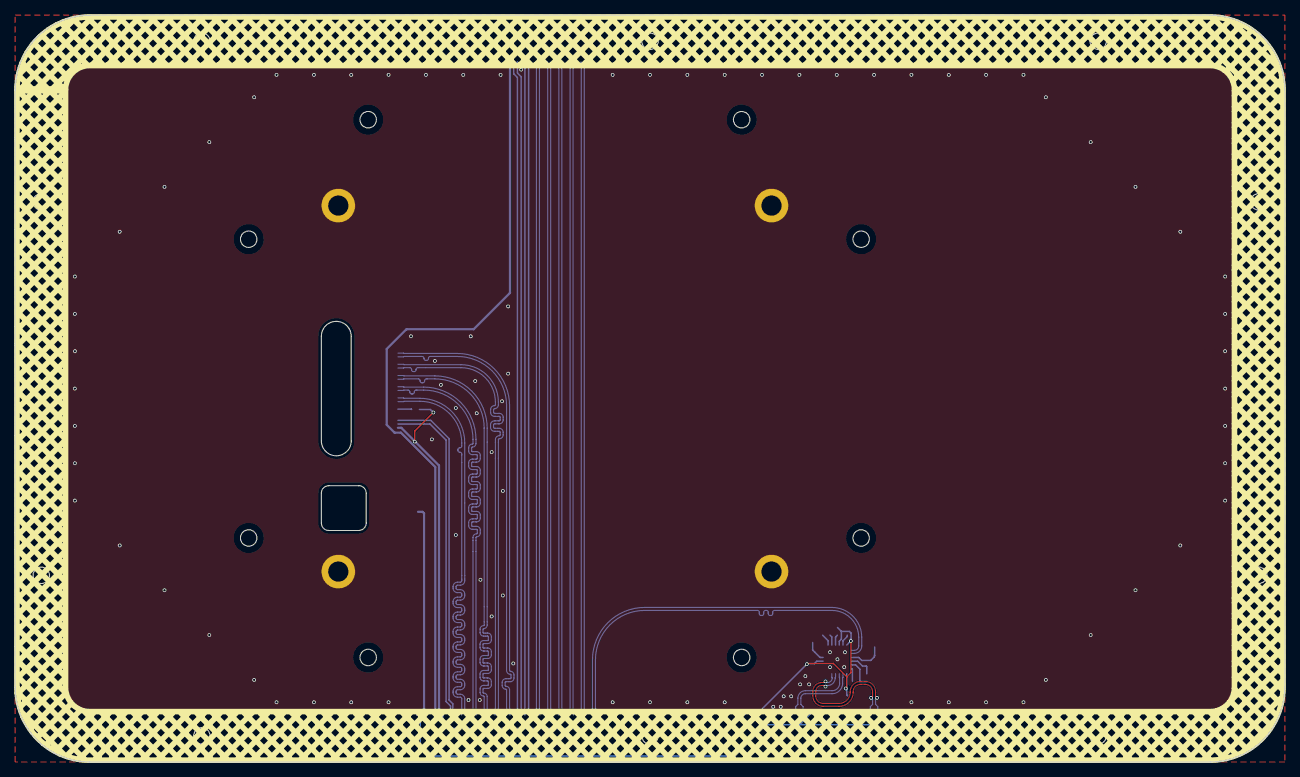
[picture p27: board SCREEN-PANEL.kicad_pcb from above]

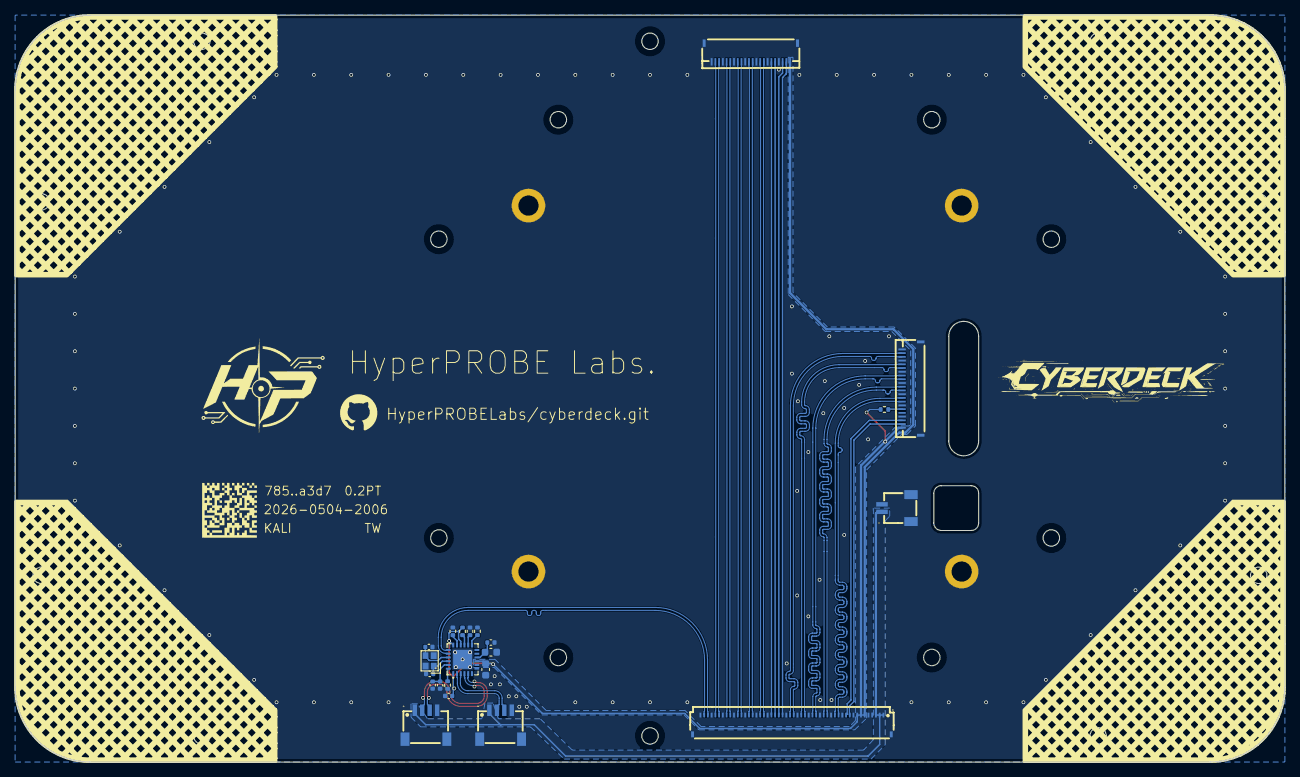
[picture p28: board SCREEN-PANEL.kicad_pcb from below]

Board: 2 copper layers, 170.0 x 100.0 mm, 44 parts (22 on the bottom side), 45 nets.

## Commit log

2026-04-22 add the screen-panel-support-rod design and production files
    [bom.csv, rod-body.step, rod-body.stl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]
2026-04-22 BOM item inc.
    [bom.csv]
2026-04-23 BOM No. remane
    [bom.csv]
2026-04-27 add the screen panel msin design and production files
    [base-plate.step, main-frame-angle-bracket-tpu.step, main-frame-angle-bracket-tpu.stl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]
2026-04-29 add screen panel pcb design and production files
    [BOM-SCREEN-PANEL.csv, SCREEN-PANEL.kicad_pcb, SCREEN-PANEL.kicad_sch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]
2026-05-04 rerouted the screen panel pairs
    [SCREEN-PANEL.kicad_pcb, SCREEN-PANEL.kicad_sch, USB2.0HUB.kicad_sch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]
